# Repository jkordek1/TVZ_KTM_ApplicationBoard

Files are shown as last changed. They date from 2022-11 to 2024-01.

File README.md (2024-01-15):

# TVZ_KTM_ApplicationBoard
 

[]()



Expansion board for two Nucleo 64 boards (master and slave), developed in 2022 for students studying at Zagreb university of applied sciences.
It enables quick and easy firmware development without the need of connecting different modules via breadboard and jumpers.

## Images
<p align="center">
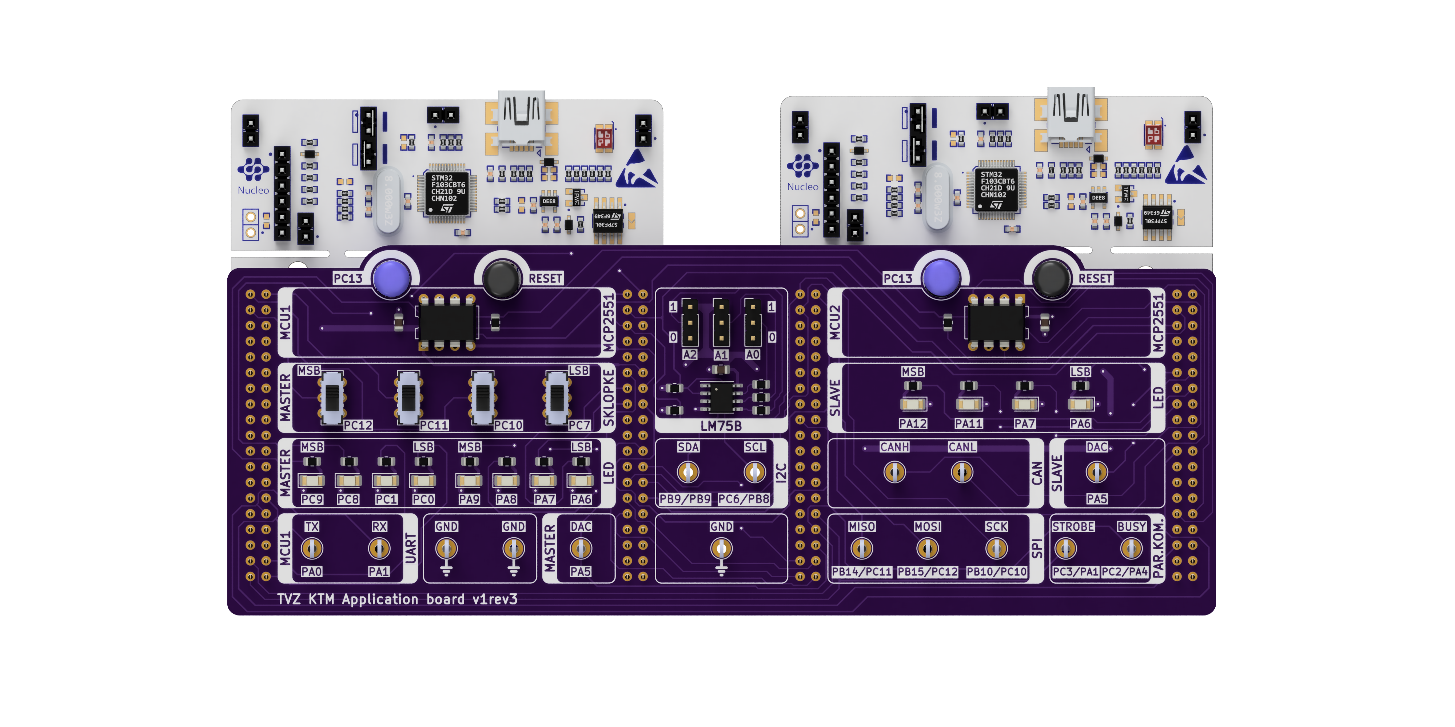
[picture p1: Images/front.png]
 
</p>

 ## Features
 - Toggle switches
 - LEDs
 - MCP2551 high-speed CAN transceiver
 - Digital I2C temperature sensor with address selection jumpers
 - UART, CAN, Parallel, analog, SPI and I2C communications between master and slave
 - Probe clips for easy oscilloscope connections
 
 ## Folder structure
    .
    ├── ...
    ├── 3d models               # 3D models of components
    ├── Images                  # Images of the project
    ├── KiCAD files             # Main KiCAD project folder
    │   ├── Datasheet           # Datasheet collection
    │   ├── jlcpcb              # jlcpcb production files
    │   ├── Graphics            # Custom graphics for PCB
    │   └── gerber              # gerber output folder
    └── ...

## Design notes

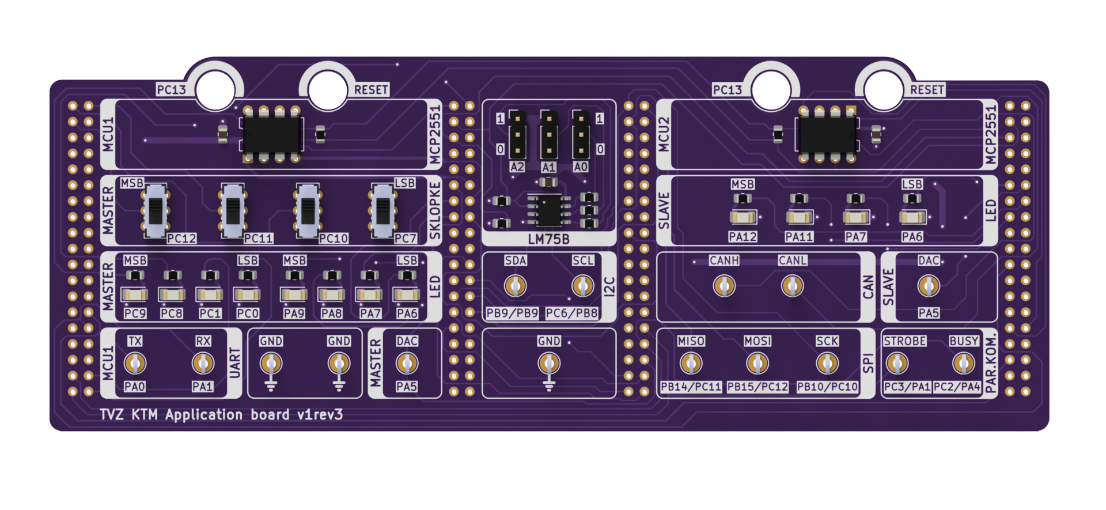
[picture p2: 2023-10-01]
KiCAD files/image render.PNG

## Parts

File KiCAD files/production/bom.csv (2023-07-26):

Designator | Footprint | Quantity | Value | LCSC Part #
C1, C2, C3 | 0805 | 3 | 100n X7R
D1, D2, D3, D4 | 1206 | 4 | BLUE
D10, D11, D12, D9 | 1206 | 4 | RED
D13 | 1206 | 1 | boja
D5, D6, D7, D8 | 1206 | 4 | GREEN
JP1, JP2, JP3 | PinHeader_1x03_P2.54mm_Vertical | 3 | Jumper_3_Open
R1, R2 | 0805 | 2 | 4k7
R10, R11, R12, R13, R14, R15, R16, R17, R18, R19, R20, R6, R7, R8, R9 | 0805 | 15 | 220
R3, R4, R5 | 0805 | 3 | 10k
SW1, SW2, SW3, SW4 | EG1271A | 4 | EG1271A
TP1, TP10, TP11, TP12, TP13, TP14, TP15, TP2, TP3, TP4, TP5, TP6, TP7, TP8, TP9 | KEYS4952 | 15 | TestPoint
U1 | SO-8_3.9x4.9mm_P1.27mm | 1 | LM75B
U2, U3 | DIP-8_W7.62mm | 2 | MCP2551-I-P
U4, U5 | NUCLEO64 | 2 | NUCLEO64-F446RE

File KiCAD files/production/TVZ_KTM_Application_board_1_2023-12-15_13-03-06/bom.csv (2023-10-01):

Designator | Footprint | Quantity | Value | LCSC Part #
C1, C2, C3 | 0805 | 3 | 100n X7R
D1, D2, D3, D4 | 1206 | 4 | BLUE
D10, D11, D12, D9 | 1206 | 4 | RED
D5, D6, D7, D8 | 1206 | 4 | GREEN
JP1, JP2, JP3 | PinHeader_1x03_P2.54mm_Vertical | 3 | Jumper_3_Open
R1, R2 | 0805 | 2 | 4k7
R10, R11, R12, R13, R14, R15, R16, R17 | 0805 | 8 | 750
R18, R19 | 0805 | 2 | 220
R3, R4, R5 | 0805 | 3 | 10k
R6, R7, R8, R9 | 0805 | 4 | 300
SW1, SW2, SW3, SW4 | EG1271A | 4 | EG1271A
TP1, TP10, TP11, TP12, TP13, TP14, TP15, TP16, TP2, TP3, TP4, TP5, TP6, TP7, TP8, TP9 | KEYS4952 | 16 | TestPoint
U1 | SO-8_3.9x4.9mm_P1.27mm | 1 | LM75B
U2, U3 | DIP-8_W7.62mm | 2 | MCP2551-I-P
U4, U5 | NUCLEO64 | 2 | NUCLEO64-F446RE

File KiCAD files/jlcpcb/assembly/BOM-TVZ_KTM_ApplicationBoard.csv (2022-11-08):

Comment | Designator | Footprint | LCSC
LM75B | U1 | SO-8_3.9x4.9mm_P1.27mm
10k | RV1 | Potentiometer_Bourns_3386P_Vertical
220 | R19 | R_0603_1608Metric
220 | R18 | R_0603_1608Metric
220 | R17 | R_0603_1608Metric
220 | R16 | R_0603_1608Metric
220 | R15 | R_0603_1608Metric
220 | R14 | R_0603_1608Metric
220 | R13 | R_0603_1608Metric
220 | R12 | R_0603_1608Metric
220 | R11 | R_0603_1608Metric
220 | R10 | R_0603_1608Metric
220 | R9 | R_0603_1608Metric
220 | R8 | R_0603_1608Metric
220 | R7 | R_0603_1608Metric
220 | R6 | R_0603_1608Metric
10k | R5 | R_0603_1608Metric
10k | R4 | R_0603_1608Metric
10k | R3 | R_0603_1608Metric
4k7 | R2 | R_0603_1608Metric
4k7 | R1 | R_0603_1608Metric
Jumper_3_Open | JP5 | PinHeader_1x03_P2.54mm_Vertical
Jumper_3_Open | JP4 | PinHeader_1x03_P2.54mm_Vertical
Jumper_2_Open | JP3 | PinHeader_1x02_P2.54mm_Vertical
Jumper_2_Open | JP2 | PinHeader_1x02_P2.54mm_Vertical
Jumper_3_Open | JP1 | PinHeader_1x03_P2.54mm_Vertical
MCP2551-I-P | U3 | DIP-8_W7.62mm
OS102011MS2QN1 | SW4 | OS102011MS2QN1
OS102011MS2QN1 | SW3 | OS102011MS2QN1
OS102011MS2QN1 | SW2 | OS102011MS2QN1
OS102011MS2QN1 | SW1 | OS102011MS2QN1
RED | D12 | LED_D5.0mm
RED | D11 | LED_D5.0mm
RED | D10 | LED_D5.0mm
RED | D9 | LED_D5.0mm
100n X7R | C4 | C_0603_1608Metric
100n X7R | C3 | C_0603_1608Metric
100n X7R | C2 | C_0603_1608Metric
GREEN | D8 | LED_D5.0mm
GREEN | D7 | LED_D5.0mm
GREEN | D6 | LED_D5.0mm
GREEN | D5 | LED_D5.0mm
BLUE | D4 | LED_D5.0mm
BLUE | D3 | LED_D5.0mm
BLUE | D2 | LED_D5.0mm
BLUE | D1 | LED_D5.0mm
100n X7R | C1 | C_0603_1608Metric
MCP2551-I-P | U2 | DIP-8_W7.62mm
Conn_02x19_Odd_Even | J2 | PinSocket_2x19_P2.54mm_Vertical_SMD
Conn_02x19_Odd_Even | J3 | PinSocket_2x19_P2.54mm_Vertical_SMD
Conn_02x19_Odd_Even | J4 | PinSocket_2x19_P2.54mm_Vertical_SMD
Conn_02x19_Odd_Even | J1 | PinSocket_2x19_P2.54mm_Vertical_SMD

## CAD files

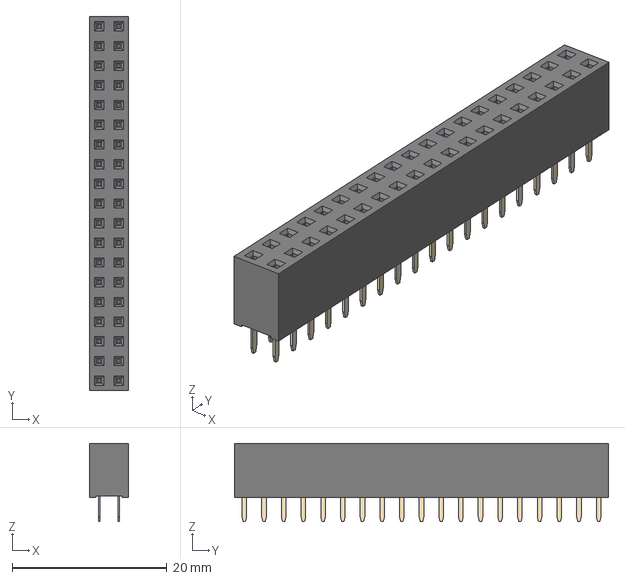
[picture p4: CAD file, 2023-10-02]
3d models/PinSocket_2x19_P2.54mm_Vertical.step
5.08 x 48.3 x 10.1 mm

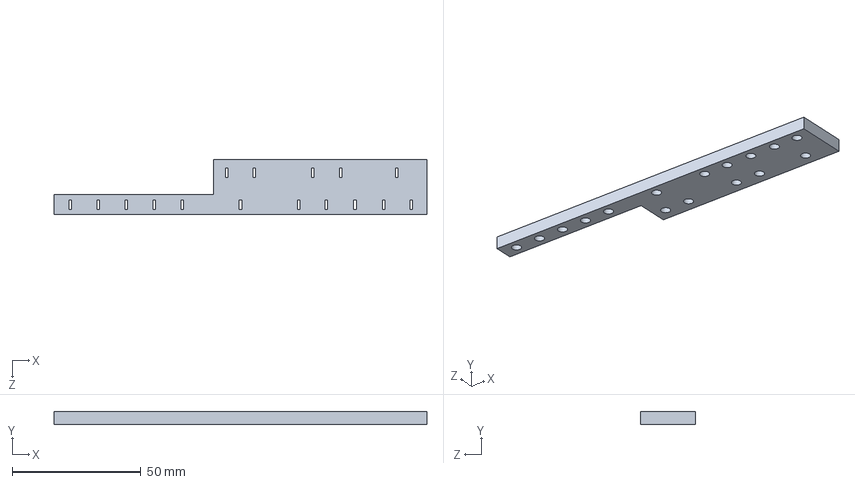
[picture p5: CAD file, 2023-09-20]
3d models/soldering.SLDPRT
145.0 x 5.00 x 21.2 mm

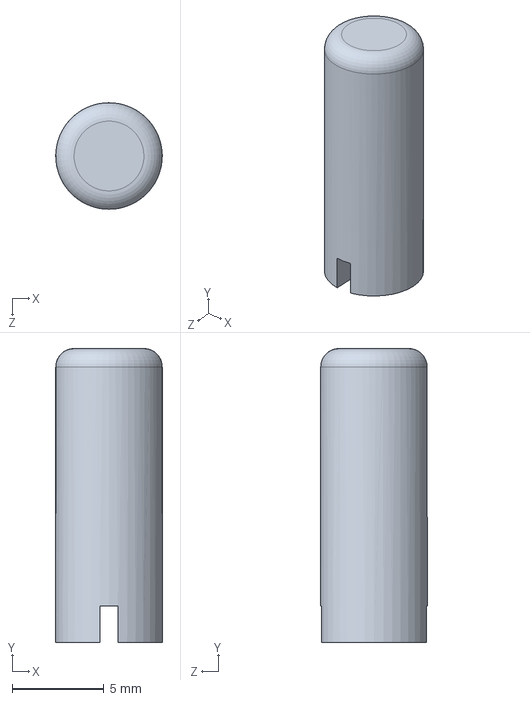
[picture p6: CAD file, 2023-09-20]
3d models/TVZ-KTM-Board-tipkala.SLDPRT
5.80 x 16.0 x 5.80 mm

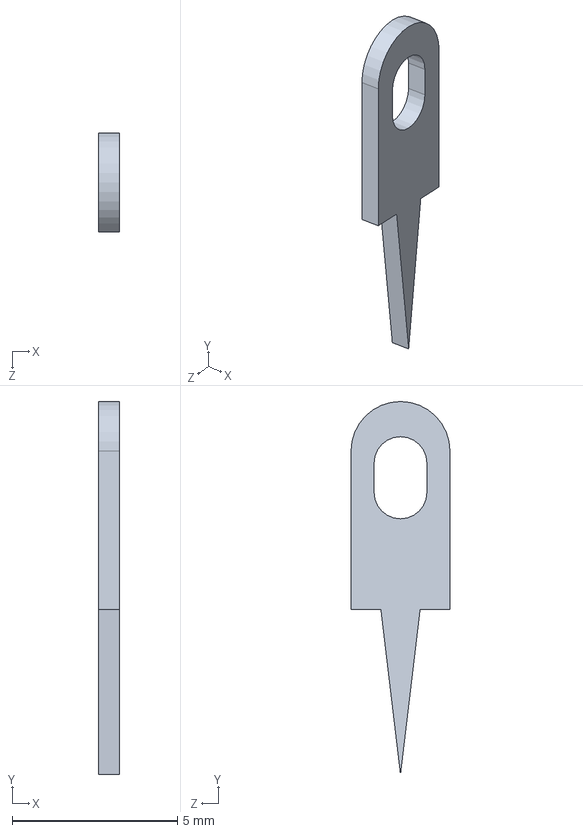
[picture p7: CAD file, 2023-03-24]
3d models/Part2.SLDPRT
0.63 x 11.3 x 3.00 mm

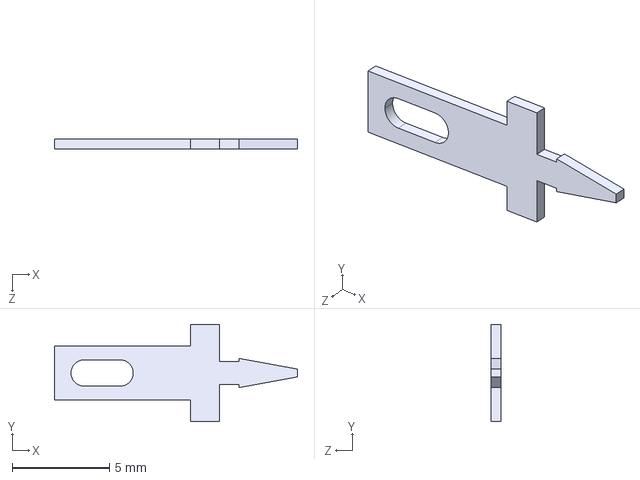
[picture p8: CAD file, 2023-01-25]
3d models/terminal-flat.STEP
12.5 x 5.00 x 0.5 mm

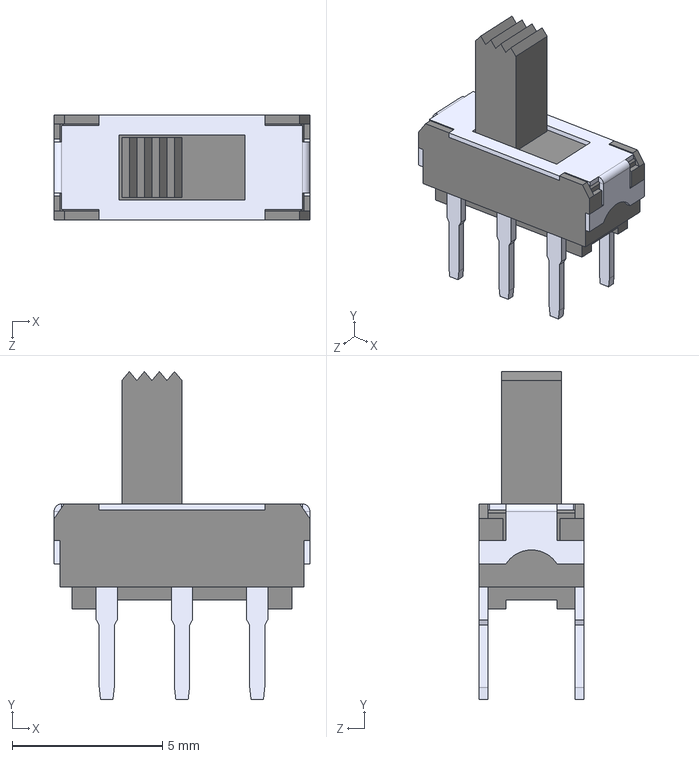
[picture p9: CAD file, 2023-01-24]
3d models/EG1271A.STEP
8.50 x 10.9 x 3.50 mm

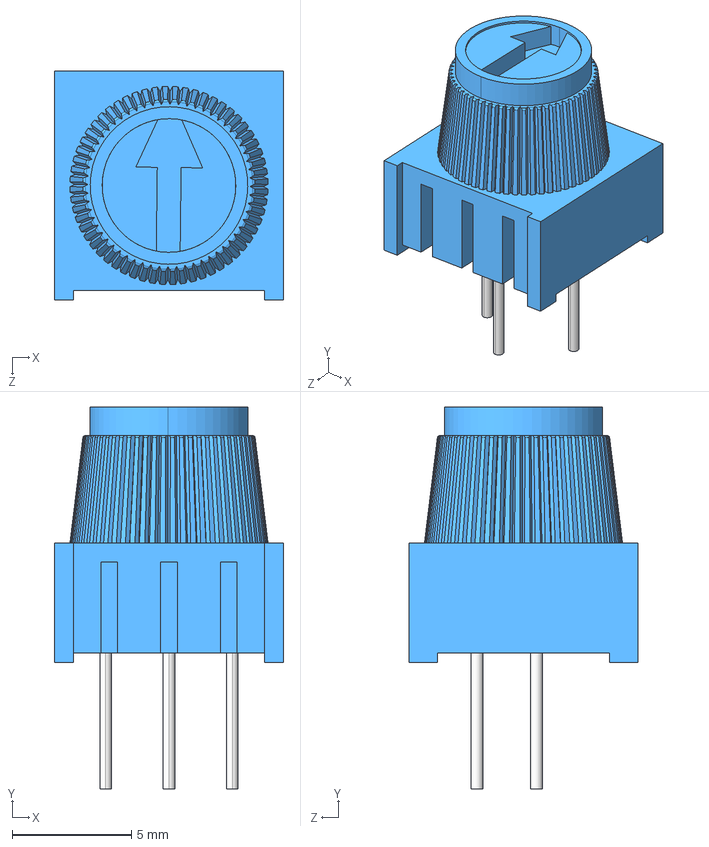
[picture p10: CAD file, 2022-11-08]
3d models/10 KILO-OHM BREADBOARD TRIM POTENTIOMETER WITH KNOB.STEP
9.60 x 16.0 x 9.60 mm
BASE, 10 KILO-OHM BREADBOARD TRIM POTENTIOMETER WITH KNOB
KNOB, 10 KILO-OHM BREADBOARD TRIM POTENTIOMETER WITH KNOB

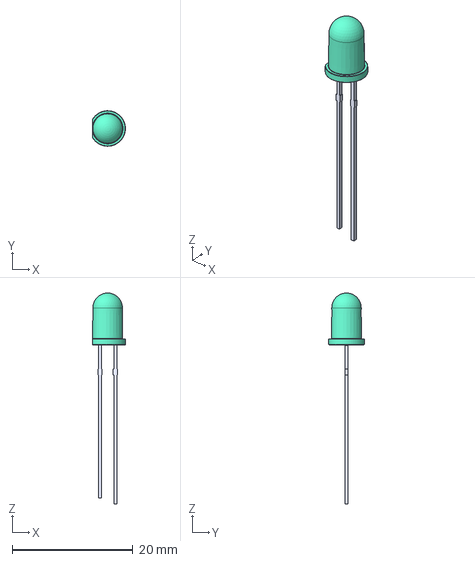
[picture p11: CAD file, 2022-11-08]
3d models/LED D5 - Green.step
5.45 x 5.90 x 35.0 mm

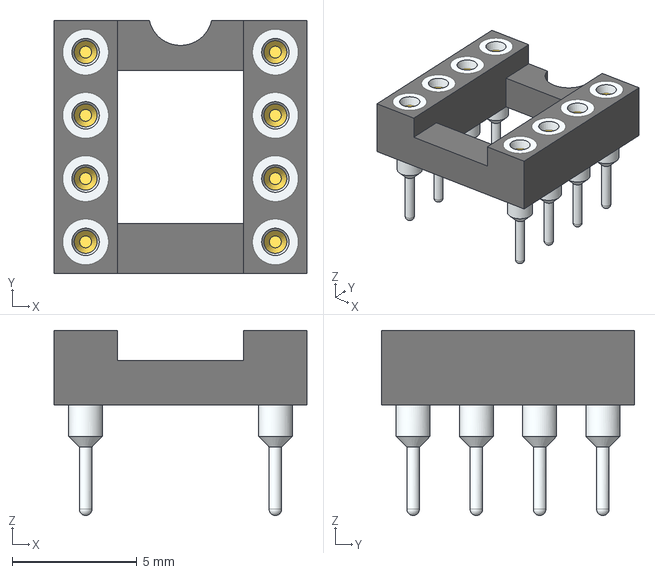
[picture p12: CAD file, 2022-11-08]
3d models/AR08-HZL-TT.stp
10.2 x 10.2 x 7.43 mm

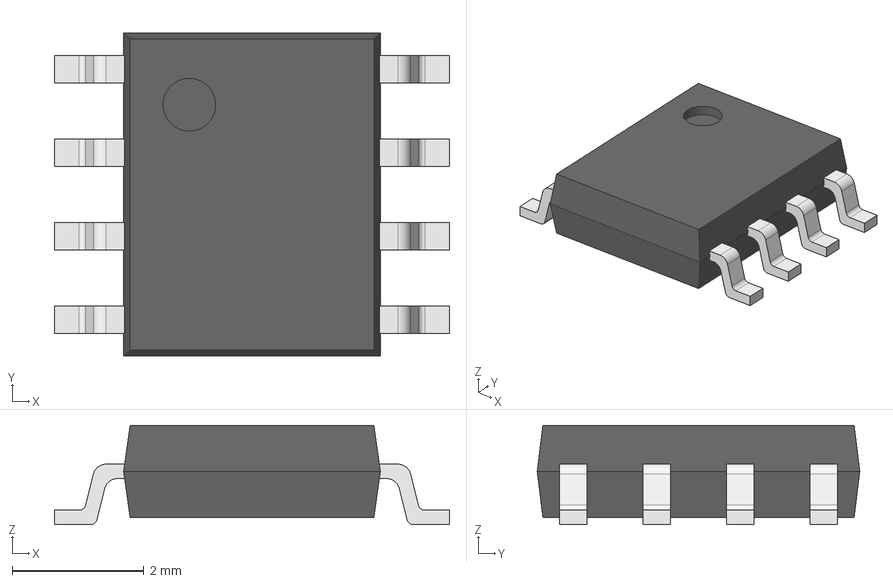
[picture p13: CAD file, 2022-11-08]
3d models/SOIC-8.step
6.00 x 4.90 x 1.51 mm

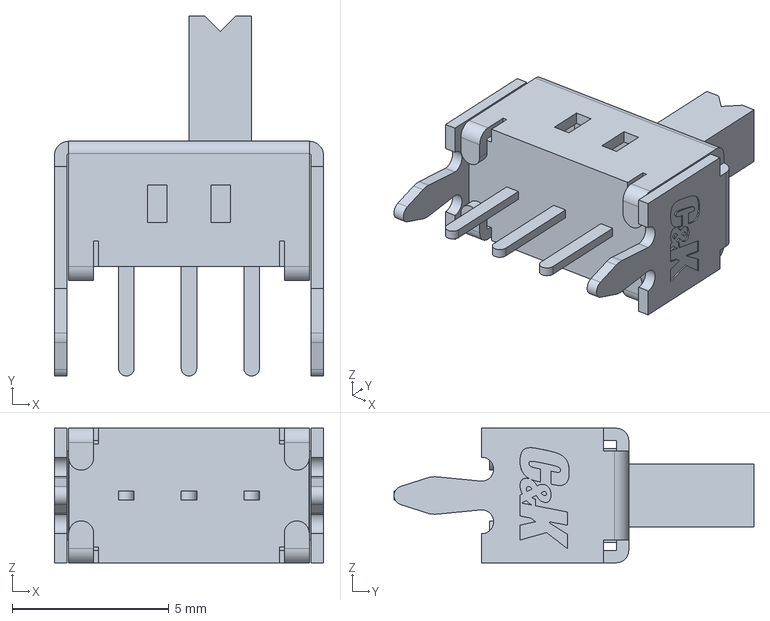
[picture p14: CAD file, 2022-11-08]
3d models/OS102011MS2QN1.stp
8.60 x 11.5 x 4.30 mm

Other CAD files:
3d models/KEYS4952.STEP
3d models/LED D5 - Blue.step
3d models/LED D5 - Red.step
3d models/terminal-flat.SLDPRT

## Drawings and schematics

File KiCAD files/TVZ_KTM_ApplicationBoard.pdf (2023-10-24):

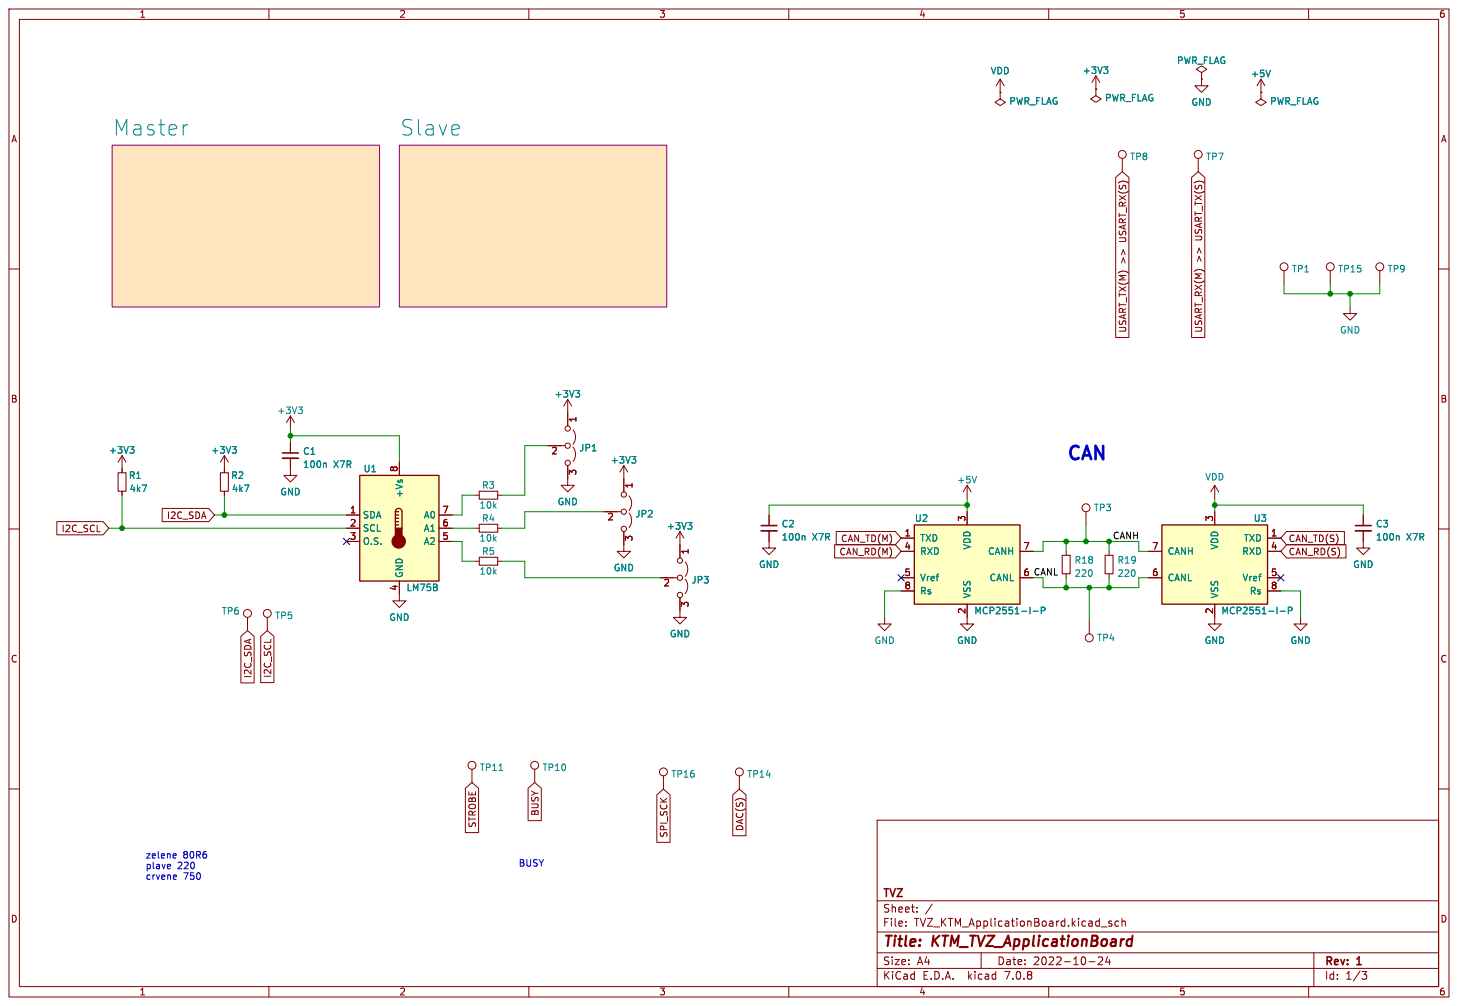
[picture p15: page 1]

3 RXD 4 Vref 5 CANL 6 CANH 7 Rs 8 GND GND

3 RXD 4 Vref 5 CANL 6 CANH 7 Rs 8 U2 MCP2551-I-P

3 RXD 4 Vref 5 CANL 6 CANH 7 Rs 8 U3 MCP2551-I-P GND

3 RXD 4 Vref 5 CANL 6 CANH 7 Rs 8 GND

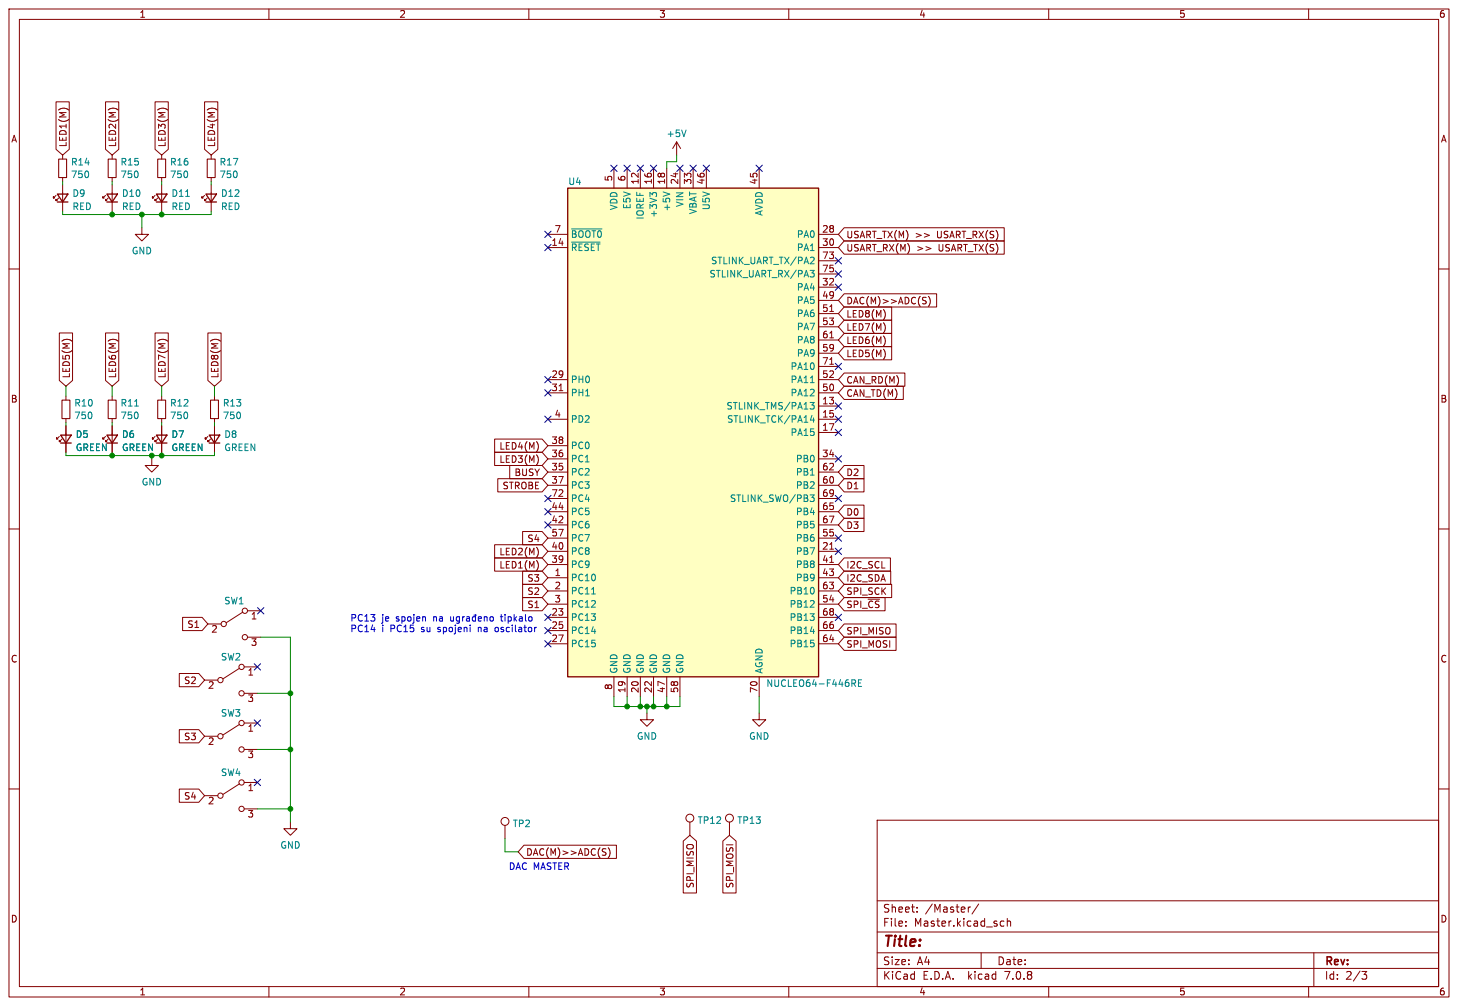
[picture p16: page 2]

LED7(M) PC13 je spojen na þÿugraeno tipkalo PC14 i PC15 su spojeni na oscilator DAC MASTER
D7 GREEN

Id: 2/3 Title: File: Master.kicad_sch Sheet: /Master/

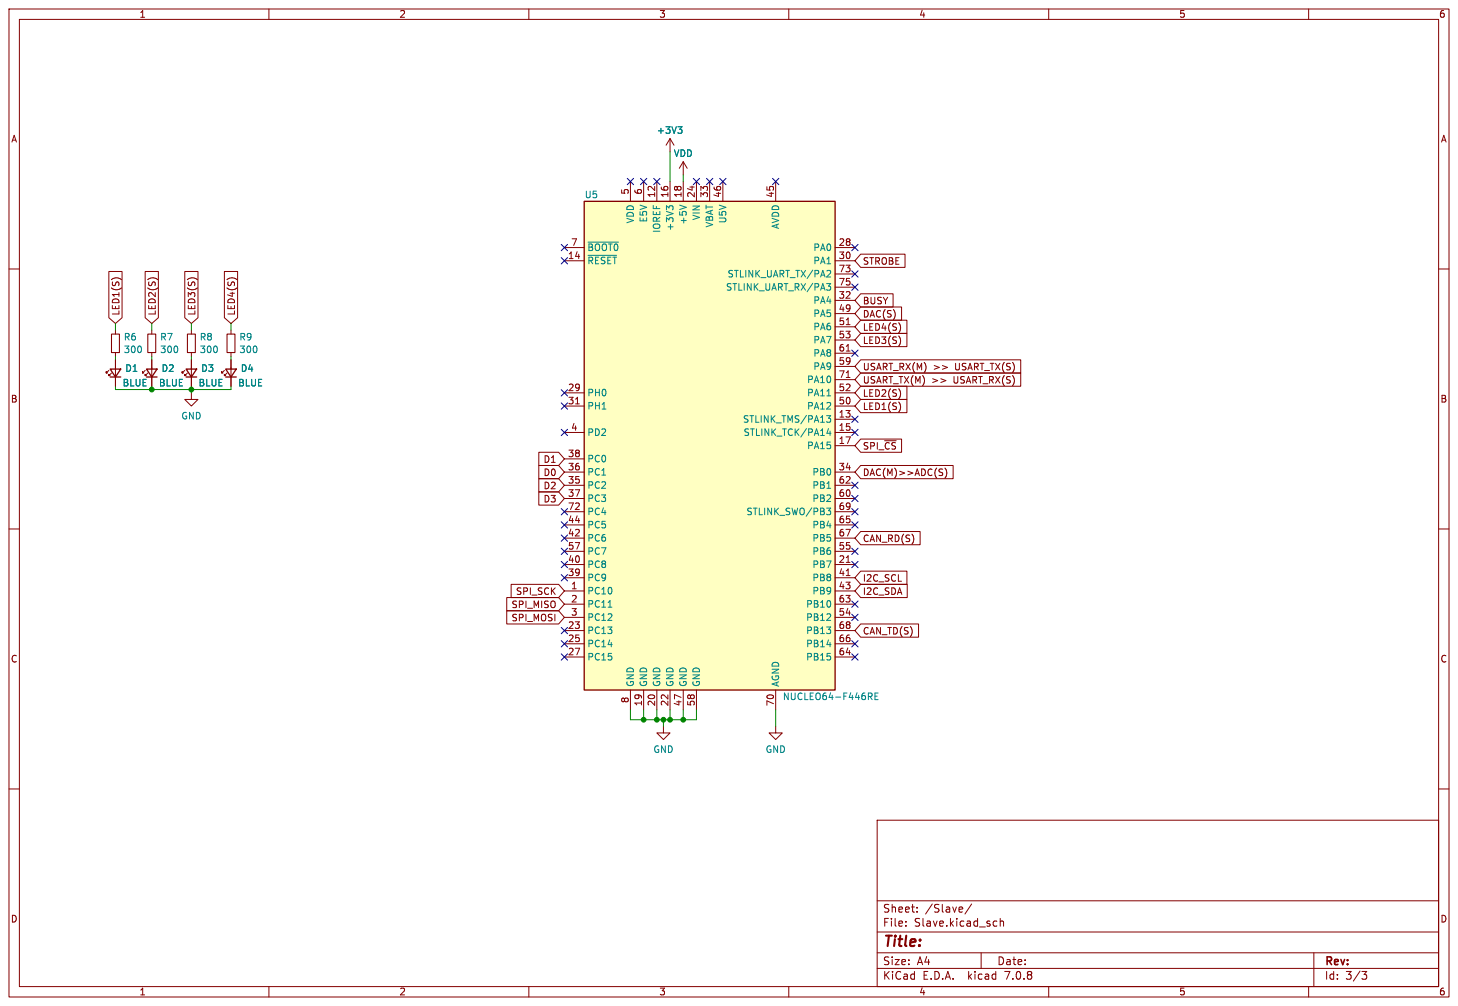
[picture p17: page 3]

Id: 3/3 Title: File: Slave.kicad_sch Sheet: /Slave/

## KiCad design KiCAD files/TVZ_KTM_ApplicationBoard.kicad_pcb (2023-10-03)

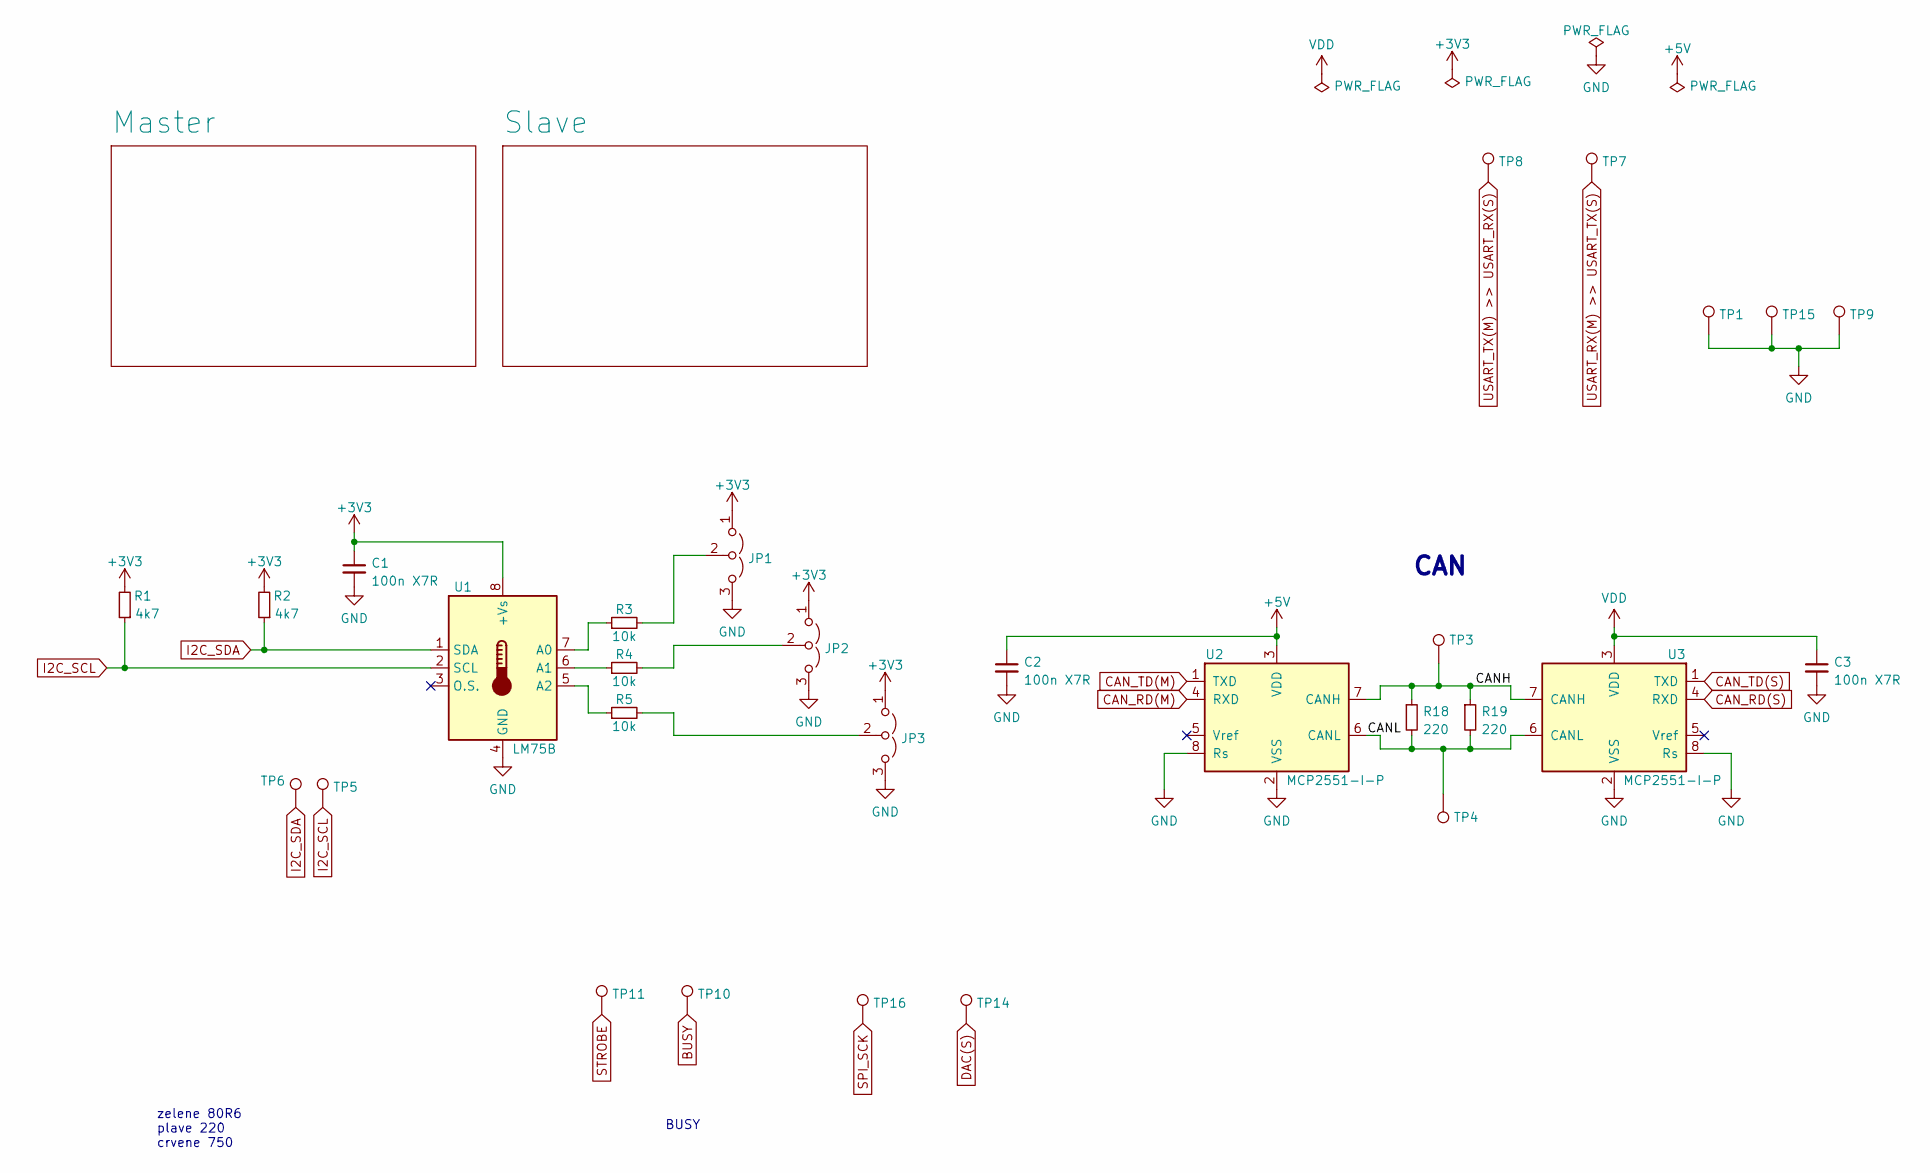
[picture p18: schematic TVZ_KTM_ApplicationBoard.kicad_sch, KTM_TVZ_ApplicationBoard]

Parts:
C1, C2, C3: 100n X7R; C_0805_2012Metric
JP1, JP2, JP3: Jumper_3_Open; PinHeader_1x03_P2.54mm_Vertical
R1, R2: 4k7; R_0805_2012Metric
R3, R4, R5: 10k; R_0805_2012Metric
R18, R19: 220; R_0805_2012Metric
TP1, TP3, TP4, TP5, TP6, TP7, TP8, TP9, TP10, TP11, TP14, TP15, TP16: TestPoint; KEYS4952
U1: LM75B; SO-8_3.9x4.9mm_P1.27mm
U2, U3: MCP2551-I-P; DIP-8_W7.62mm

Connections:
+3V3: C1.1, JP1.1 (A), JP2.1 (A), JP3.1 (A), R1.2, R2.2, U1.8 (+Vs); also elsewhere on the board
+5V: C2.1, U2.3 (VDD); also elsewhere on the board
/CANH: R18.1, R19.1, TP3.1, U2.7 (CANH), U3.7 (CANH)
/CANL: R18.2, R19.2, TP4.1, U2.6 (CANL), U3.6 (CANL)
BUSY: TP10.1; also elsewhere on the board
CAN_RD(M): U2.4 (RXD); also elsewhere on the board
CAN_RD(S): U3.4 (RXD); also elsewhere on the board
CAN_TD(M): U2.1 (TXD); also elsewhere on the board
CAN_TD(S): U3.1 (TXD); also elsewhere on the board
DAC(S): TP14.1; also elsewhere on the board
GND: C1.2, C2.2, C3.2, JP1.3 (B), JP2.3 (B), JP3.3 (B), TP1.1, TP9.1, TP15.1, U1.4 (GND), U2.2 (VSS), U2.8 (Rs), U3.2 (VSS), U3.8 (Rs); also elsewhere on the board
I2C_SCL: R1.1, TP5.1, U1.2 (SCL); also elsewhere on the board
I2C_SDA: R2.1, TP6.1, U1.1 (SDA); also elsewhere on the board
unnamed: JP1.2 (C), R3.2
unnamed: JP2.2 (C), R4.2
unnamed: JP3.2 (C), R5.2
unnamed: R3.1, U1.7 (A0)
unnamed: R4.1, U1.6 (A1)
unnamed: R5.1, U1.5 (A2)
SPI_SCK: TP16.1; also elsewhere on the board
STROBE: TP11.1; also elsewhere on the board
USART_RX(M) >> USART_TX(S): TP7.1; also elsewhere on the board
USART_TX(M) >> USART_RX(S): TP8.1; also elsewhere on the board
VDD: C3.1, U3.3 (VDD); also elsewhere on the board

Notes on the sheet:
CAN
BUSY
zelene 80R6 plave 220 crvene 750

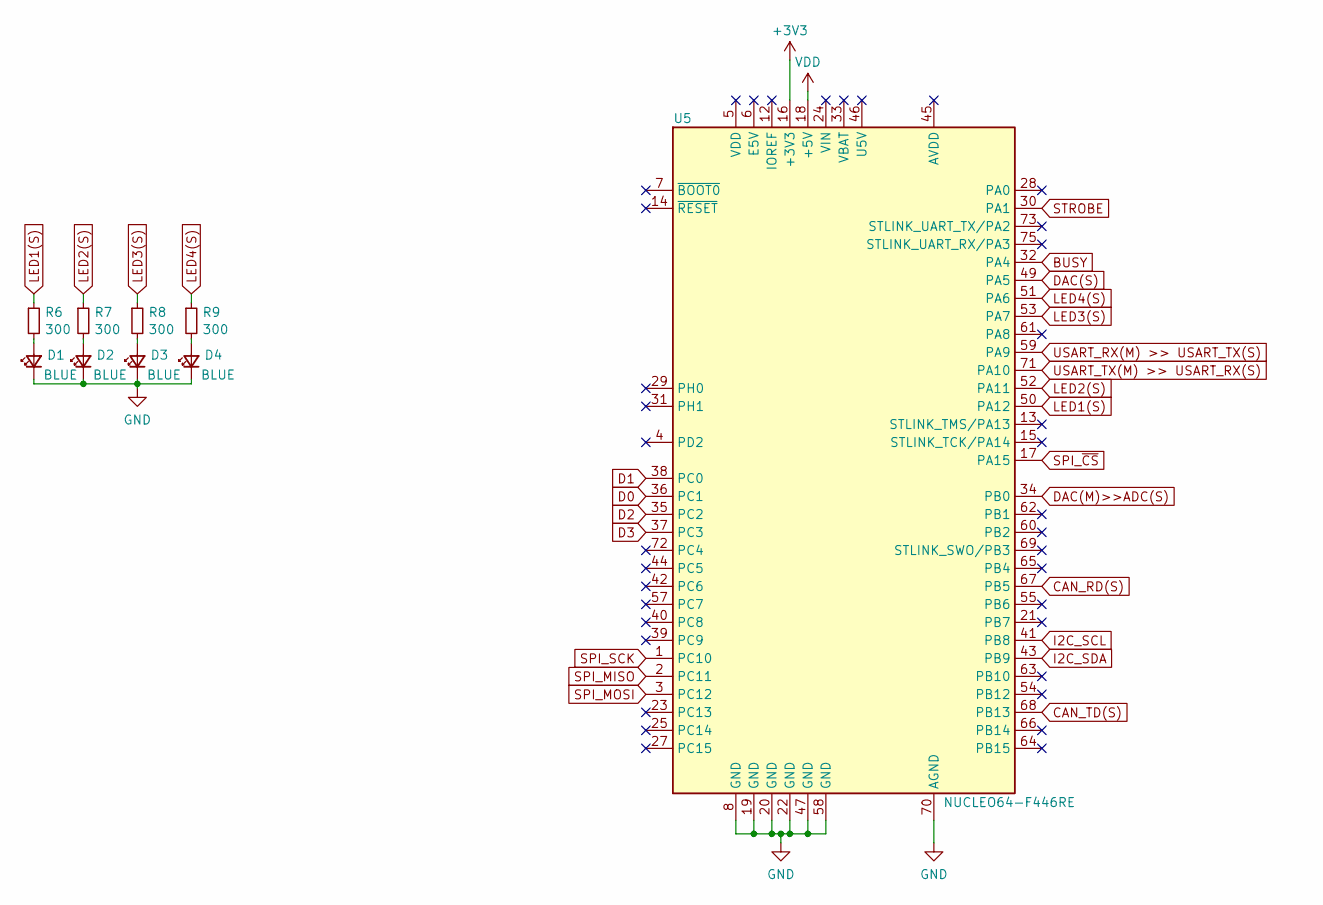
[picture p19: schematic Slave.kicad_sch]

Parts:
D1, D2, D3, D4: BLUE; LED_1206_3216Metric
R6, R7, R8, R9: 300; R_0805_2012Metric
U5: NUCLEO64-F446RE; NUCLEO64

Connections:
+3V3: U5.16 (+3V3); also elsewhere on the board
BUSY: U5.32 (PA4); also elsewhere on the board
CAN_RD(S): U5.67 (PB5); also elsewhere on the board
CAN_TD(S): U5.68 (PB13); also elsewhere on the board
D0: U5.36 (PC1); also elsewhere on the board
D1: U5.38 (PC0); also elsewhere on the board
D2: U5.35 (PC2); also elsewhere on the board
D3: U5.37 (PC3); also elsewhere on the board
DAC(M)>>ADC(S): U5.34 (PB0); also elsewhere on the board
DAC(S): U5.49 (PA5); also elsewhere on the board
GND: D1.1 (K), D2.1 (K), D3.1 (K), D4.1 (K), U5.8 (GND), U5.19 (GND), U5.20 (GND), U5.22 (GND), U5.47 (GND), U5.58 (GND), U5.70 (AGND); also elsewhere on the board
I2C_SCL: U5.41 (PB8); also elsewhere on the board
I2C_SDA: U5.43 (PB9); also elsewhere on the board
LED1(S): R6.1, U5.50 (PA12)
LED2(S): R7.1, U5.52 (PA11)
LED3(S): R8.1, U5.53 (PA7)
LED4(S): R9.1, U5.51 (PA6)
unnamed: D1.2 (A), R6.2
unnamed: D2.2 (A), R7.2
unnamed: D3.2 (A), R8.2
unnamed: D4.2 (A), R9.2
SPI_MISO: U5.2 (PC11); also elsewhere on the board
SPI_MOSI: U5.3 (PC12); also elsewhere on the board
SPI_SCK: U5.1 (PC10); also elsewhere on the board
SPI_~CS: U5.17 (PA15); also elsewhere on the board
STROBE: U5.30 (PA1); also elsewhere on the board
USART_RX(M) >> USART_TX(S): U5.59 (PA9); also elsewhere on the board
USART_TX(M) >> USART_RX(S): U5.71 (PA10); also elsewhere on the board
VDD: U5.18 (+5V); also elsewhere on the board

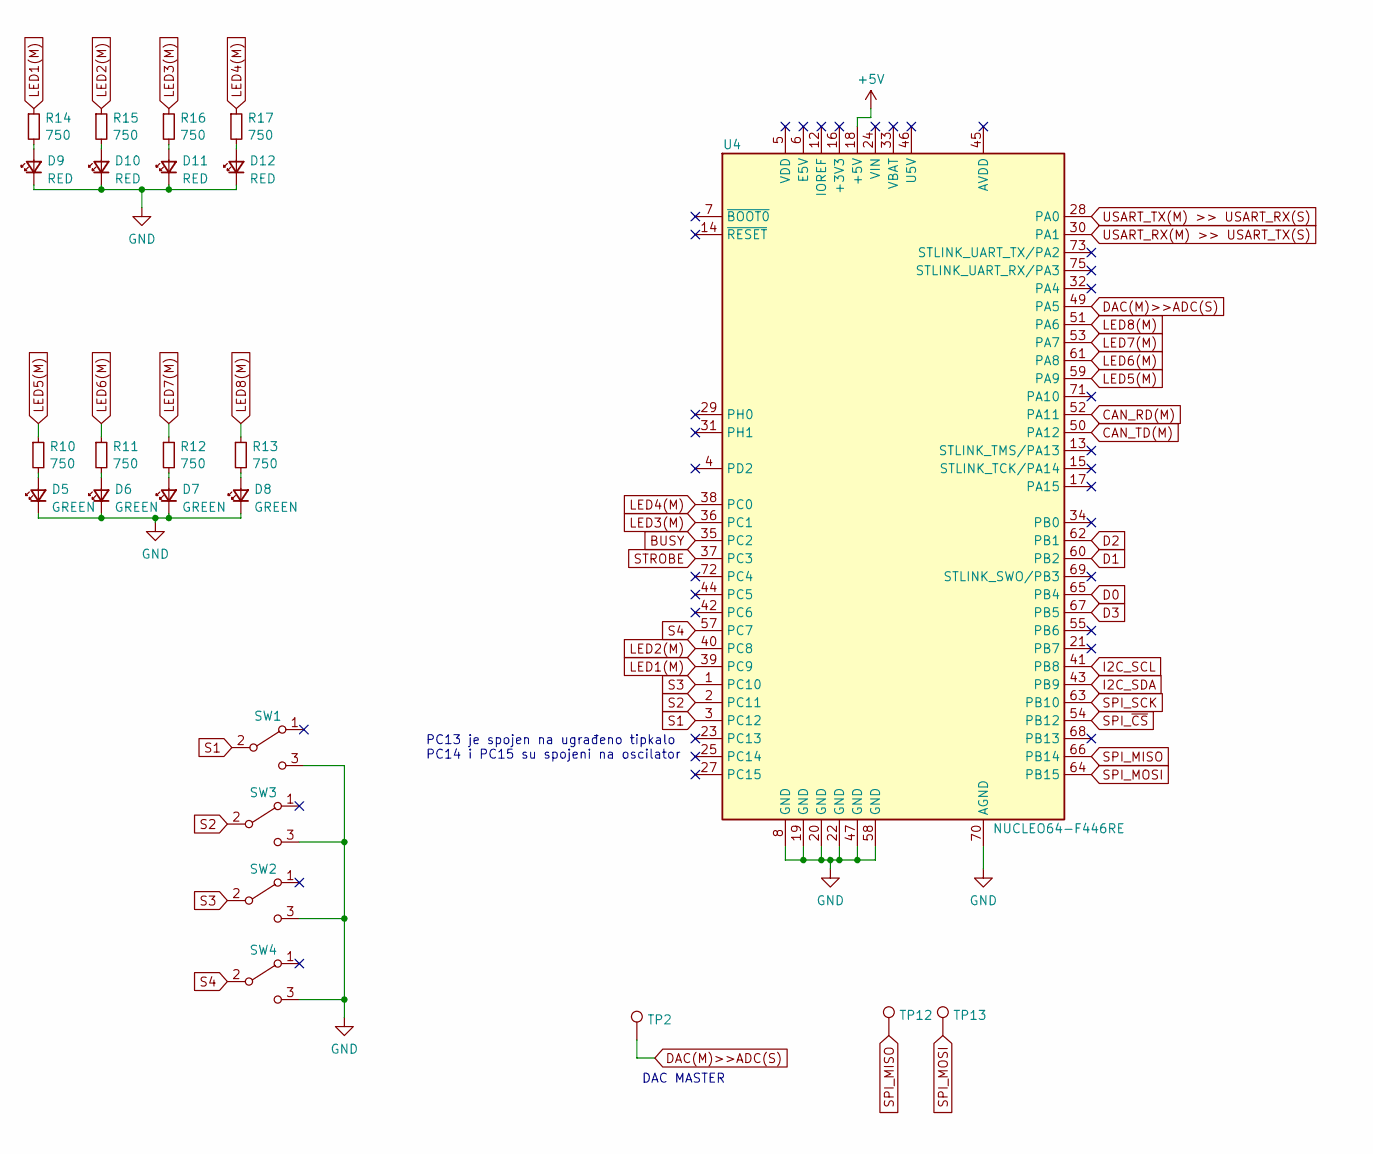
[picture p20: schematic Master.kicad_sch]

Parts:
D5, D6, D7, D8: GREEN; LED_1206_3216Metric
D9, D10, D11, D12: RED; LED_1206_3216Metric
R10, R11, R12, R13, R14, R15, R16, R17: 750; R_0805_2012Metric
SW1, SW2, SW3, SW4: EG1271A
TP2, TP12, TP13: TestPoint; KEYS4952
U4: NUCLEO64-F446RE; NUCLEO64

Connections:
+5V: U4.18 (+5V); also elsewhere on the board
BUSY: U4.35 (PC2); also elsewhere on the board
CAN_RD(M): U4.52 (PA11); also elsewhere on the board
CAN_TD(M): U4.50 (PA12); also elsewhere on the board
D0: U4.65 (PB4); also elsewhere on the board
D1: U4.60 (PB2); also elsewhere on the board
D2: U4.62 (PB1); also elsewhere on the board
D3: U4.67 (PB5); also elsewhere on the board
DAC(M)>>ADC(S): TP2.1, U4.49 (PA5); also elsewhere on the board
GND: D5.1 (K), D6.1 (K), D7.1 (K), D8.1 (K), D9.1 (K), D10.1 (K), D11.1 (K), D12.1 (K), SW1.3 (C), SW2.3 (C), SW3.3 (C), SW4.3 (C), U4.8 (GND), U4.19 (GND), U4.20 (GND), U4.22 (GND), U4.47 (GND), U4.58 (GND), U4.70 (AGND); also elsewhere on the board
I2C_SCL: U4.41 (PB8); also elsewhere on the board
I2C_SDA: U4.43 (PB9); also elsewhere on the board
LED1(M): R14.1, U4.39 (PC9)
LED2(M): R15.1, U4.40 (PC8)
LED3(M): R16.1, U4.36 (PC1)
LED4(M): R17.1, U4.38 (PC0)
LED5(M): R10.1, U4.59 (PA9)
LED6(M): R11.1, U4.61 (PA8)
LED7(M): R12.1, U4.53 (PA7)
LED8(M): R13.1, U4.51 (PA6)
unnamed: D5.2 (A), R10.2
unnamed: D6.2 (A), R11.2
unnamed: D7.2 (A), R12.2
unnamed: D8.2 (A), R13.2
unnamed: D9.2 (A), R14.2
unnamed: D10.2 (A), R15.2
unnamed: D11.2 (A), R16.2
unnamed: D12.2 (A), R17.2
S1: SW1.2 (B), U4.3 (PC12)
S4: SW4.2 (B), U4.57 (PC7)
SPI_MISO: TP12.1, U4.66 (PB14); also elsewhere on the board
SPI_MOSI: TP13.1, U4.64 (PB15); also elsewhere on the board
SPI_SCK: U4.63 (PB10); also elsewhere on the board
SPI_~CS: U4.54 (PB12); also elsewhere on the board
STROBE: U4.37 (PC3); also elsewhere on the board
USART_RX(M) >> USART_TX(S): U4.30 (PA1); also elsewhere on the board
USART_TX(M) >> USART_RX(S): U4.28 (PA0); also elsewhere on the board

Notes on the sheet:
DAC MASTER
PC13 je spojen na ugrađeno tipkalo PC14 i PC15 su spojeni na oscilator

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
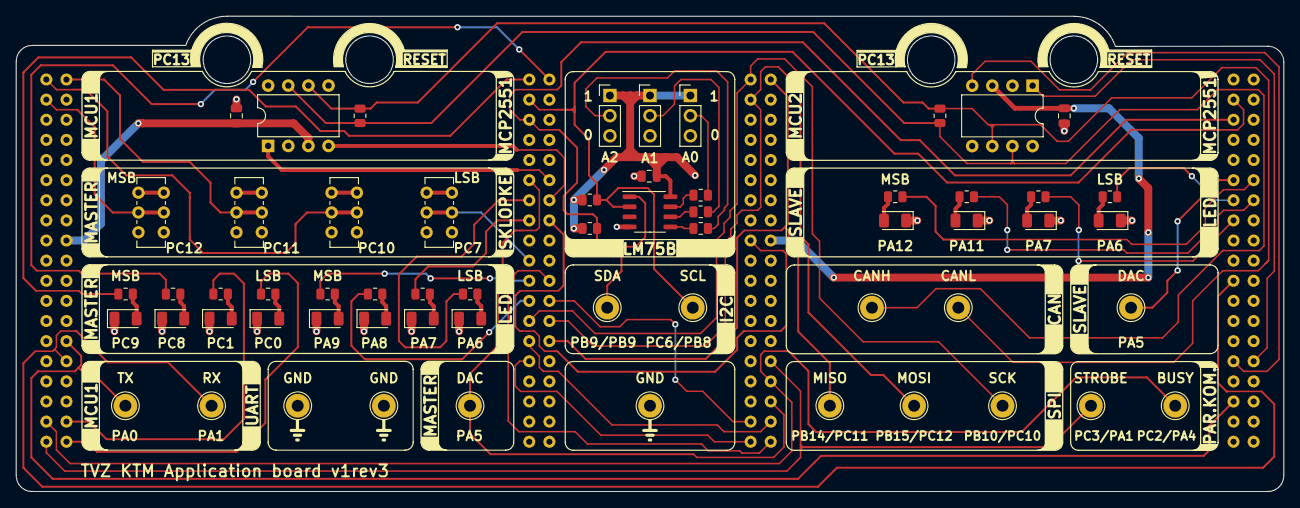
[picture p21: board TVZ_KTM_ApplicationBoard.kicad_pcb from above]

Board: 2 copper layers, 160.0 x 60.0 mm, 62 parts (0 on the bottom side), 60 nets.

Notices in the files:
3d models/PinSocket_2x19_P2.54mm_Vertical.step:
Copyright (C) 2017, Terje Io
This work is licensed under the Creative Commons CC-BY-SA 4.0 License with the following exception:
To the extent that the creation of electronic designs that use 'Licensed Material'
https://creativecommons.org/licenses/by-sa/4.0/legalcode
